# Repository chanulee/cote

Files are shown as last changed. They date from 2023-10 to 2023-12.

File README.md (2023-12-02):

# cote
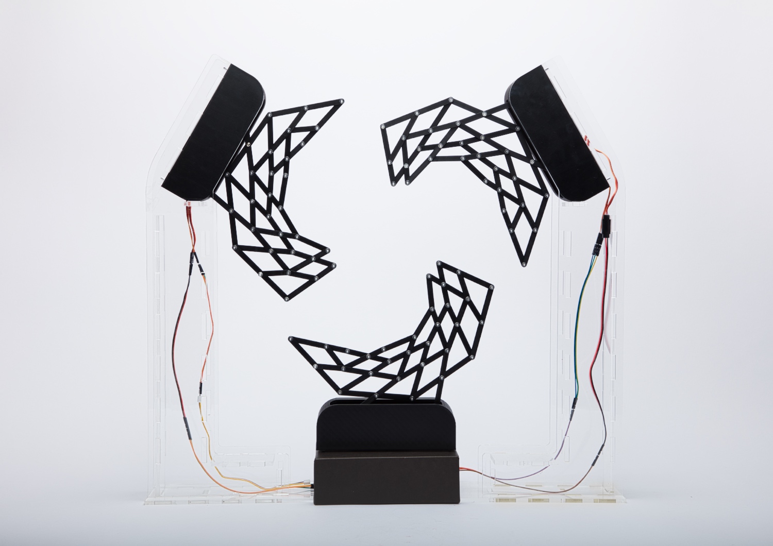
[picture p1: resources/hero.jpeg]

**_What is the value of telepresence if actual presence is neglected?_**  
  
During the pandemic, people became accustomed to virtual interactions. Driven by this shift, emerging technologies like Virtual Reality are focusing on translating real-world experiences entirely into the digital realm. Meanwhile, face-to-face interactions in the real world are dwindling. As an example, we often observe families in cafes who are each just looking at their smartphone without any conversation. What is the value of telepresence if actual presence is neglected? Tim Cook once said, if you're staring at smartphones more than into people's eyes, you're doing it wrong. We aim to gently promote humane and analog interaction through calm physical interfaces rather than attention-grabbing displays.  
  
In the Korean language, Hangeul, there's a phrase, "대화를 꽃피우다," which translates to 'blooming the conversation.' It's a beautiful term that likens a conversation to a flower.
  
With this ‘côte’ in the room, it can subtly make the space more vibrant and delightful.
## 1. File Directory
- demonov01: For final demo of Cyber Physical Systems module happened in 01 Nov 2023. oF, ino, wek files + recreation guide
- testcode: QC tools made for the project: osc communication, serial communication and motor control
- trials: Tried to develop it part-by-part, some succeeded and some didn't. For future works.
- resources: Images and circuit diagram
- appendix: About visionOSC's face datapoints
## 2. Specimen
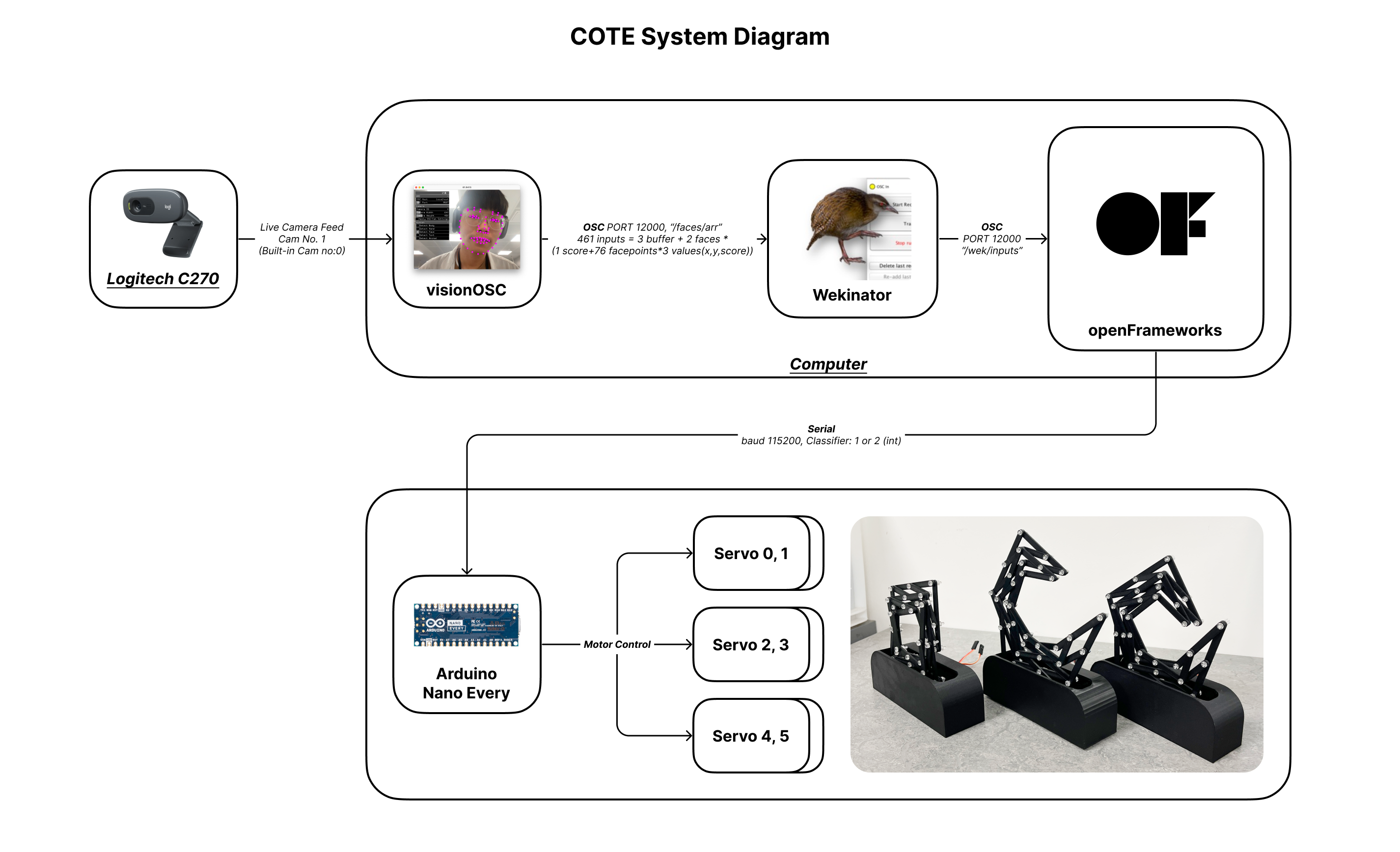
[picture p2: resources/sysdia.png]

### 2-1. Hardware
Check out fritzing file for more information.
- Arduino Nano Every (Arduino Mega 2560)
- Micro Servo MG90S (Black small one) * 6 (5V)
- Logitech C270 (HD 720p, proven to work as a video grabbing webcam) [Amazon](https://www.amazon.co.uk/dp/B01BGBJ8Y0?psc=1&ref=ppx_yo2ov_dt_b_product_details)
- PCA9685 Motor Driver (for power delivery, should be connected to power and arduino)
### 2-2. Software Requirements
- oF ofxOsc
- oF ofxGui (for Motor Testing)
- wekinator
- visionOSC [go to repo](https://github.com/LingDong-/VisionOSC)
- touchDesigner (not yet)
### 2-3. Features
- OSC Communication (visionOSC - wekinator - oF)
- Multiple OSC inputs
- OSC input parsing
- Combine multiple OSC messages and send (trying)
- Serial Communication (oF - Arduino)
- Motor Control
- Higher resolution (room to improve)
- Breathing motion
## 3. visionOSC data structure
Through several experiments with processing and wekinator OSC input monitor, I mapped out datapoints of [LingDong's visionOSC](https://github.com/LingDong-/VisionOSC).  
Check out [visionOscDatapoints folder](https://github.com/chanulee/cote-bloom/tree/main/appendix/visionOscDatapoints)
## 4. Future Works
- visionOSC & TouchDesigner --multiOSC--> oF --modifiedOSC--> wekinator --class--> oF --serial--> Arduino
- If openframeworks gets data directly from OSC not wekinator, we can make some decision before getting to the wekinator part - for example, maybe we can use certain model in certain condition - and we can exclude non-related data from the original OSC so machine learning part would be much more accurate with faster training/learning
- motor angle data 0-254 is mapped to 0-270 and finally about 1000-2000, but I'm still using 0-254 part so the resolution is quite low.
- nothing happens if there's nobody or one person in the cam view, everything stops. maybe we can add breathing motion when nothing is detected
- getting input from multiple addresses works in oF
- Selecting certain relevant OSC messages and then make them into a new message, sending it to wekinator - receiving and making new message kind of works, but the sending timing makes the message's size vary.
- Simple keypressedSerial is working on both Arduino nano and Mega - but servoAngleSerial doesn't work on Mega.
## 5. References
1. ofxOsc OSC Message documentaiton [openframeworks.cc](https://openframeworks.cc/documentation/ofxOsc/ofxOscMessage/)
2. ofxOsc bundling and parsing [forum.openframeworks.cc](https://forum.openframeworks.cc/t/osc-bundle-help/15404)
3. Based on research by H. Segerman [Paper](https://archive.bridgesmathart.org/2022/bridges2022-313.pdf)
## 6. Credits (Teammates)
- Hardware design engineering mainly by Jinhak Lee (IDE 23/25)
- Virtual prototyping, visual design and circuit diagram mainly by Poh Asdathorn (GIDv / Keio Media Design)
---
**Cyber Physical Systems, October-November 2023**    
Advisor Dr. Rebecca Stewart, Charlotte Slingsby, Dr Shayan Sharifi   
MSc Innovation Design Engineering   
Dyson School of Design Engineering, Imperial College London  
  
This module was funded by [Design Education Trust](https://www.designeducationtrust.org.uk/)

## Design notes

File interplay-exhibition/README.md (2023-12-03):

# System Guide for Cote
This system guide is for 
1. Software Setup
2. Hardware Installation
3. Maintenance
## 1. Software Setup for exhibition scenario 
### Essential Softwares
As Cote uses Apple's CoreML for face tracking, it is recommended to use Apple computers for the recreation. (If it's not possible, use faceOSC instead)  
1. Update your macbook and download Xcode. For this exhibition, I'm using macOS Sonoma and Xcode 15.
2. Download wekinator [here](http://www.wekinator.org/downloads/)
3. Download openFrameworks [here](https://openframeworks.cc/download/) and move it to main HD directory
4. Download visionOSC [here](https://github.com/LingDong-/VisionOSC)
### Essential Configurations
1. Download wek2ardu **oF** project from [here](https://github.com/chanulee/cote/tree/d52dcc5865f60ab2a6a312d79a86d98ab8011d35/demonov01), move the entire project to /myApps
2. Download coteClass.ino and upload it to **arduino**
3. Open **visionOSC**, turn off every detection except face detection, check port no 9527 (visionOSC to Wekinator) and save.
4. Connect the **webcam**, change the cammera number to get camera feed - do this every time you set up the system. (Due to refreshing and the fact that the camera number might vary on different system.
5. Open **wekinator**  

| Command | Input | Output |
| --- | --- | --- |
| `port` | 9527 | 12000 (default) |
| `add` | /faces/arr | /wek/outputs (default) |
| `#` | 232 | 1 |
|`description` | visionOSC -> Wek | Wek -> oF, Classifier with 2 classes |
## 2. Hardware Installation
- Macbook Pro 15 + USB-C Charger
- Control Box (arduino and PCA9685 motor driver) + Motor driver power
- Cote Modules * 3
- Webcam (Logitech C270) + USB-A to C Converter
## 3. Maintenance
### Setting up the artwork
Every hardware should be wired
1. Turn on the macbook, hold 'option' until it gets into bootcamp. Select macOS.
2. Open **visionOSC**, **wek2arduDebug**, **wekinator** and **macs fan control**
3. Setting up the webcam: On **visionOSC**, Press "Apply OSC/CAM Settings" button. Webcam's light turns on when successful.
4. In **wekinator**, press CMD+O or File/Open Project... and select interplay1p.wekproj. See if there's 232 inputs and the input light becomes green.
5. On the status bar, open **macs fan control**, set the fan speed to 4500 for both fans
6. Don't close the macbook all the way, it will prevent the heat to vent. Turn down the brightness and gently leave it open about 40 degree.
### End of the day...
1. Close **visionOSC**, **wek2arduDebug** and **wekinator**
2. Turn off the macbook and close it
### In case of...
- Hardware stuck: gently push the stuck part to the position it should be
- Software issue: please contact the creators
---
**InterPlay Exhibition Information**
- Venue: The Royal Society of Sculptors, Dora House 108 Old Brompton Rd, London SW7 3RA
- The Design Education Trust, Royal Society of Sculptors
  
Do you ever stop to reflect how much the design of motion in everyday objects affects your daily routine? Have you ever thought that behind everyday actions there was a creative mind designing the motion?  
Firstly you will encounter a selection of experimental kinetic objects from ‘Cyber Physical Systems’; a workshop of the joint programmes at Imperial College and the Royal College of Art of Innovation Design Engineering and Global Innovation Design. The devices use Arduino computers and Ai software to propose speculative kinetic designs that translate human behaviour into robotic motion.  
The Design Education Trust invites you to delve into a playful experience aiming to lift your spirits in these dour times. Join us between the 5th and 9th December to see our free INTERPLAY EXHIBITION at the ROYAL SOCIETY of SCULPTORS.

---
**Cyber Physical Systems, October-November 2023**    
Advisor Dr. Rebecca Stewart, Charlotte Slingsby, Dr Shayan Sharifi   
MSc Innovation Design Engineering   
Dyson School of Design Engineering, Imperial College London  
  
This module was funded by [Design Education Trust](https://www.designeducationtrust.org.uk/)

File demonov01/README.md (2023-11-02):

# Full Demo Set for cote - 01 Nov
## 1. Working Features
- visionOSC --OSC--> Wekinator --OSC--> oF --Serial--> Arduino
- Motor Control
- Higher resolution
- Mapping
- Breathing motion
- Blooming motion
## 2. Specimen
### 2-1. Hardware
Check out fritzing file for more information.
- Arduino Nano Every (Arduino Mega 2560)
- Micro Servo MG90S (Black small one) * 6 (5V)
- Logitech C270 (HD 720p, proven to work as a video grabbing webcam) [Amazon](https://www.amazon.co.uk/dp/B01BGBJ8Y0?psc=1&ref=ppx_yo2ov_dt_b_product_details)
- PCA9685 Motor Driver (for power delivery, should be connected to power and arduino)
### 2-2. Files Description
- cote2people: wekinator model (Neural Network) that determines if two people are standing still(1) or in  face-to-face(2)
- wek2ardu: oF app that gets OSC data from wekinator(1 or 2) and send it to arduino as serial message
- coteClass: Arduino file for getting the wekinator class
## 3. Recreate the Demo
1. Open **visionOSC**, connect Logitech C270, set CAM 1 and press 'Apply' and see if video grabbing is working (default output PORT 9527, address /faces/arr, 461 inputs for 2 faces)
2. Open **wekinator** app, open(CMD+O) a machine learning model cote2people, press 'Start Listening' and see if the data input is working, and 'Run' 
3. Open **Arduino** app, open coteClass.ino and upload it to arduino nano
4. Open **wek2ardu.xcodepro**, check if the arduino serial monitor is closed, and then build it
---
**Cyber Physical Systems, October-November 2023**    
Advisor Dr. Rebecca Stewart, Charlotte Slingsby, Dr Shayan Sharifi   
MSc Innovation Design Engineering   
Dyson School of Design Engineering, Imperial College London  
  
This module was funded by [Design Education Trust](https://www.designeducationtrust.org.uk/)

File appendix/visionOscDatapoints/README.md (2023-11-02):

# visionOSC data structure
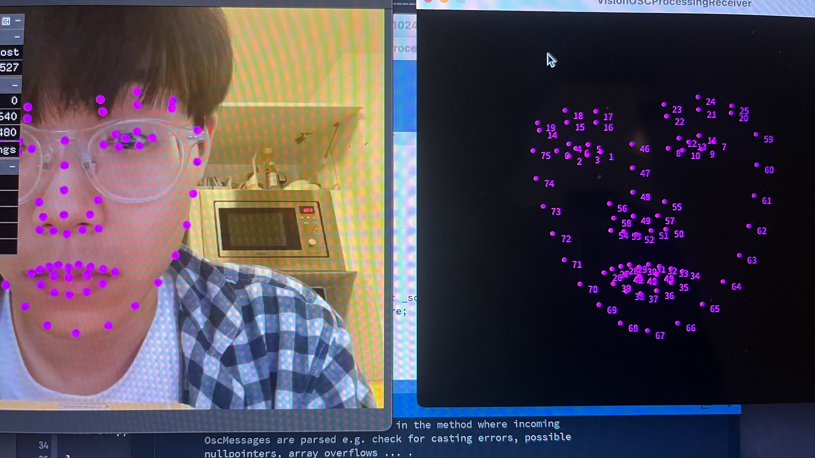
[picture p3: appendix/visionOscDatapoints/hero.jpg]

This is datapoint map/guide for faceOSC in LingDong's visionOSC [go to repo](https://github.com/LingDong-/VisionOSC).
- 232 inputs for one face, 461 inputs for two faces.
- Check out the .csv file for the specific datapoint chart.
- The score data: their numbers are 3, 6, 9...
- Buffer 0 data: 0, 1, 2
```
for (int i = 4; i <= 231; i++) {
    if (i % 3 != 0) { // Skip scores: 3, 6, 9, 12, 15, 18...
        int faceData = m.getArgAsInt(i);
        ofLog() << "facedata: " << faceData;
        wekMessage.addIntArg(faceData);
    }
}
```
## 1. Background
- There's datapoint description for poseOSC and handOSC but no enough documentation of faceOSC
- **No information about which data is related to certain part of the face**
- So this map might be helpful for various usecases such as refining relevant data for machine learning or media art
## 2. File structure
- **Modified processing file** that maps out the number of each datapoints on the face [original code at LingDong's repo](https://github.com/LingDong-/VisionOSC/tree/main/demos/VisionOSCProcessingReceiver)
- **csv file** with all the data points
- **screenshot** of wekinator input monitor
---
Chanwoo Lee  
MSc Innovation Design Engineering,  
Imperial College London  
Oct 2023

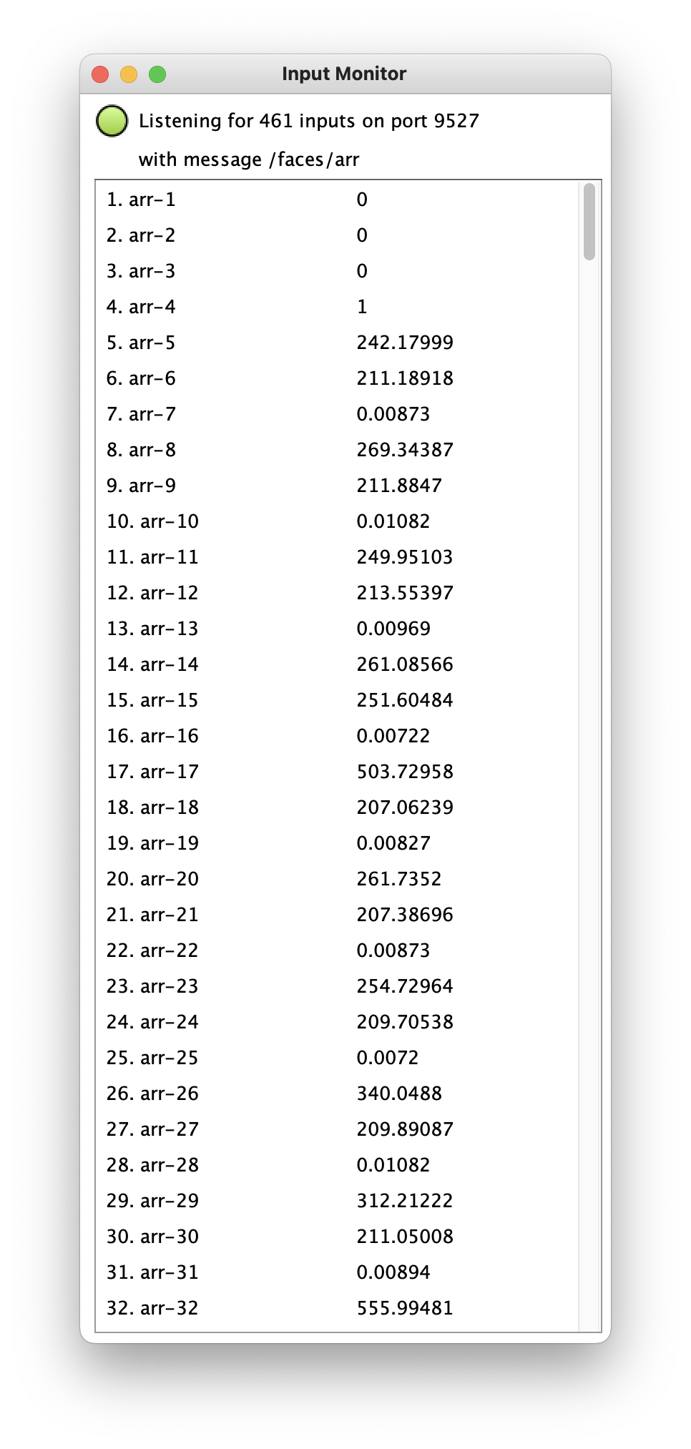
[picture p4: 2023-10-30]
appendix/visionOscDatapoints/2faces.png

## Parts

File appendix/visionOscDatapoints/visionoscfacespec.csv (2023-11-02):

no | data | bodypart
0 | width
1 | height
2 | faceno
3 | score face
4 | x | eyeL
5 | y | eyeL
6 | score | eyeL
7 | x | eyeL
8 | y | eyeL
9 | score | eyeL
10 | x | eyeL
11 | y | eyeL
12 | score | eyeL
13 | x | eyeL
14 | y | eyeL
15 | score | eyeL
16 | x | eyeL
17 | y | eyeL
18 | score | eyeL
19 | x | eyeL
20 | y | eyeL
21 | score | eyeL
22 | x | eyeL
23 | y | eyeL
24 | score | eyeL
25 | x | eyeR
26 | y | eyeR
27 | score | eyeR
28 | x | eyeR
29 | y | eyeR
30 | score | eyeR
31 | x | eyeR
32 | y | eyeR
33 | score | eyeR
34 | x | eyeR
35 | y | eyeR
36 | score | eyeR
37 | x | eyeR
38 | y | eyeR
39 | score | eyeR
40 | x | eyeR
41 | y | eyeR
42 | score | eyeR
43 | x | eyeR
44 | y | eyeR
45 | score | eyeR
46 | x | eyebrowL
47 | y | eyebrowL
48 | score | eyebrowL
49 | x | eyebrowL
50 | y | eyebrowL
51 | score | eyebrowL
52 | x | eyebrowL
53 | y | eyebrowL
54 | score | eyebrowL
55 | x | eyebrowL
56 | y | eyebrowL
57 | score | eyebrowL
58 | x | eyebrowL
59 | y | eyebrowL
60 | score | eyebrowL
61 | x | eyebrowL
62 | y | eyebrowL
63 | score | eyebrowL
64 | x | eyebrowR
65 | y | eyebrowR
66 | score | eyebrowR
67 | x | eyebrowR
68 | y | eyebrowR
69 | score | eyebrowR
70 | x | eyebrowR
71 | y | eyebrowR
72 | score | eyebrowR
73 | x | eyebrowR
74 | y | eyebrowR
75 | score | eyebrowR
76 | x | eyebrowR
77 | y | eyebrowR
78 | score | eyebrowR
79 | x | eyebrowR
80 | y | eyebrowR
81 | score | eyebrowR
82 | x | mouth
83 | y | mouth
84 | score | mouth
85 | x | mouth
86 | y | mouth
87 | score | mouth
88 | x | mouth
89 | y | mouth
90 | score | mouth
91 | x | mouth
92 | y | mouth
93 | score | mouth
94 | x | mouth
95 | y | mouth
96 | score | mouth
97 | x | mouth
98 | y | mouth
99 | score | mouth
100 | x | mouth
101 | y | mouth
102 | score | mouth
103 | x | mouth
104 | y | mouth
105 | score | mouth
106 | x | mouth
107 | y | mouth
108 | score | mouth
109 | x | mouth
110 | y | mouth
111 | score | mouth
112 | x | mouth
113 | y | mouth
114 | score | mouth
115 | x | mouth
116 | y | mouth
117 | score | mouth
118 | x | mouth
119 | y | mouth
120 | score | mouth
121 | x | mouth
122 | y | mouth
123 | score | mouth
124 | x | mouth
125 | y | mouth
126 | score | mouth
127 | x | mouth
128 | y | mouth
129 | score | mouth
130 | x | mouth
131 | y | mouth
132 | score | mouth
133 | x | mouth
134 | y | mouth
135 | score | mouth
136 | x | mouth
137 | y | mouth
138 | score | mouth
139 | x | mouth
140 | y | mouth
141 | score | mouth
142 | x | nose
143 | y | nose
144 | score | nose
145 | x | nose
146 | y | nose
147 | score | nose
148 | x | nose
149 | y | nose
150 | score | nose
151 | x | nose
152 | y | nose
153 | score | nose
154 | x | nose
155 | y | nose
156 | score | nose
157 | x | nose
158 | y | nose
159 | score | nose
160 | x | nose
161 | y | nose
162 | score | nose
163 | x | nose
164 | y | nose
165 | score | nose
166 | x | nose
167 | y | nose
168 | score | nose
169 | x | nose
170 | y | nose
171 | score | nose
172 | x | nose
173 | y | nose
174 | score | nose
175 | x | nose
176 | y | nose
177 | score | nose
178 | x | nose
179 | y | nose
180 | score | nose
181 | x | face outline
182 | y | face outline
183 | score | face outline
184 | x | face outline
185 | y | face outline
186 | score | face outline
187 | x | face outline
188 | y | face outline
189 | score | face outline
190 | x | face outline
191 | y | face outline
192 | score | face outline
193 | x | face outline
194 | y | face outline
195 | score | face outline
196 | x | face outline
197 | y | face outline
198 | score | face outline
199 | x | face outline
200 | y | face outline
201 | score | face outline
202 | x | face outline
203 | y | face outline
204 | score | face outline
205 | x | face outline
206 | y | face outline
207 | score | face outline
208 | x | face outline
209 | y | face outline
210 | score | face outline
211 | x | face outline
212 | y | face outline
213 | score | face outline
214 | x | face outline
215 | y | face outline
216 | score | face outline
217 | x | face outline
218 | y | face outline
219 | score | face outline
220 | x | face outline
221 | y | face outline
222 | score | face outline
223 | x | face outline
224 | y | face outline
225 | score | face outline
226 | x | face outline
227 | y | face outline
228 | score | face outline
229 | x | face outline
230 | y | face outline
231 | score | face outline
232 | score face
233 | x | eyeL
234 | y | eyeL
235 | score | eyeL
236 | x | eyeL
237 | y | eyeL
238 | score | eyeL
239 | x | eyeL
240 | y | eyeL
241 | score | eyeL
242 | x | eyeL
243 | y | eyeL
244 | score | eyeL
245 | x | eyeL
246 | y | eyeL
247 | score | eyeL
248 | x | eyeL
249 | y | eyeL
250 | score | eyeL
251 | x | eyeL
252 | y | eyeL
253 | score | eyeL
254 | x | eyeR
255 | y | eyeR
256 | score | eyeR
257 | x | eyeR
258 | y | eyeR
259 | score | eyeR
260 | x | eyeR
261 | y | eyeR
262 | score | eyeR
263 | x | eyeR
264 | y | eyeR
265 | score | eyeR
266 | x | eyeR
267 | y | eyeR
268 | score | eyeR
269 | x | eyeR
270 | y | eyeR
271 | score | eyeR
272 | x | eyeR
273 | y | eyeR
274 | score | eyeR
275 | x | eyebrowL
276 | y | eyebrowL
277 | score | eyebrowL
278 | x | eyebrowL
279 | y | eyebrowL
280 | score | eyebrowL
281 | x | eyebrowL
282 | y | eyebrowL
283 | score | eyebrowL
284 | x | eyebrowL
285 | y | eyebrowL
286 | score | eyebrowL
287 | x | eyebrowL
288 | y | eyebrowL
289 | score | eyebrowL
290 | x | eyebrowL
291 | y | eyebrowL
292 | score | eyebrowL
293 | x | eyebrowR
294 | y | eyebrowR
295 | score | eyebrowR
296 | x | eyebrowR
297 | y | eyebrowR
298 | score | eyebrowR
299 | x | eyebrowR
300 | y | eyebrowR
301 | score | eyebrowR
302 | x | eyebrowR
303 | y | eyebrowR
304 | score | eyebrowR
305 | x | eyebrowR
306 | y | eyebrowR
307 | score | eyebrowR
308 | x | eyebrowR
309 | y | eyebrowR
310 | score | eyebrowR
311 | x | mouth
312 | y | mouth
313 | score | mouth
314 | x | mouth
315 | y | mouth
316 | score | mouth
317 | x | mouth
318 | y | mouth
319 | score | mouth
320 | x | mouth
321 | y | mouth
322 | score | mouth
323 | x | mouth
324 | y | mouth
325 | score | mouth
326 | x | mouth
327 | y | mouth
328 | score | mouth
329 | x | mouth
330 | y | mouth
331 | score | mouth
332 | x | mouth
333 | y | mouth
334 | score | mouth
335 | x | mouth
336 | y | mouth
337 | score | mouth
338 | x | mouth
339 | y | mouth
340 | score | mouth
341 | x | mouth
342 | y | mouth
343 | score | mouth
344 | x | mouth
345 | y | mouth
346 | score | mouth
347 | x | mouth
348 | y | mouth
349 | score | mouth
350 | x | mouth
351 | y | mouth
352 | score | mouth
353 | x | mouth
354 | y | mouth
355 | score | mouth
356 | x | mouth
357 | y | mouth
358 | score | mouth
359 | x | mouth
360 | y | mouth
361 | score | mouth
362 | x | mouth
363 | y | mouth
364 | score | mouth
365 | x | mouth
366 | y | mouth
367 | score | mouth
368 | x | mouth
369 | y | mouth
370 | score | mouth
371 | x | nose
372 | y | nose
373 | score | nose
374 | x | nose
375 | y | nose
376 | score | nose
377 | x | nose
378 | y | nose
379 | score | nose
380 | x | nose
381 | y | nose
382 | score | nose
383 | x | nose
384 | y | nose
385 | score | nose
386 | x | nose
387 | y | nose
388 | score | nose
389 | x | nose
390 | y | nose
391 | score | nose
392 | x | nose
393 | y | nose
394 | score | nose
395 | x | nose
396 | y | nose
397 | score | nose
398 | x | nose
399 | y | nose
400 | score | nose
401 | x | nose
402 | y | nose
403 | score | nose
404 | x | nose
405 | y | nose
406 | score | nose
407 | x | nose
408 | y | nose
409 | score | nose
410 | x | face outline
411 | y | face outline
412 | score | face outline
413 | x | face outline
414 | y | face outline
415 | score | face outline
416 | x | face outline
417 | y | face outline
418 | score | face outline
419 | x | face outline
420 | y | face outline
421 | score | face outline
422 | x | face outline
423 | y | face outline
424 | score | face outline
425 | x | face outline
426 | y | face outline
427 | score | face outline
428 | x | face outline
429 | y | face outline
430 | score | face outline
431 | x | face outline
432 | y | face outline
433 | score | face outline
434 | x | face outline
435 | y | face outline
436 | score | face outline
437 | x | face outline
438 | y | face outline
439 | score | face outline
440 | x | face outline
441 | y | face outline
442 | score | face outline
443 | x | face outline
444 | y | face outline
445 | score | face outline
446 | x | face outline
447 | y | face outline
448 | score | face outline
449 | x | face outline
450 | y | face outline
451 | score | face outline
452 | x | face outline
453 | y | face outline
454 | score | face outline
455 | x | face outline
456 | y | face outline
457 | score | face outline
458 | x | face outline
459 | y | face outline
460 | score | face outline

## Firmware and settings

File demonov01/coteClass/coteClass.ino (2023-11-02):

#include <Servo.h>

/*---Servo Declare---*/
// twelve servo objects can be created on most boards
Servo servoSet1;
int lM1 = 15;
int rM1 = 16;
Servo servoSet2;
int lM2 = 17;
int rM2 = 18;
Servo servoSet3;
int lM3 = 19;
int rM3 = 20;

int angle = 0;

/*---State---*/
// enum State {
//   Idle,
//   Ascending,
//   BigBreathe,
//   Descending,
//   Idle2,
//   Ascending2,
//   BigBreathe2,
//   Descending2
// };
// State state = Idle;

/*---State in number---*/
int state = 3;
/*
  3Idle,
  4Ascending,
  5BigBreathe,
  6Descending,
  7Idle2,
  8Ascending2,
  9BigBreathe2,
  10Descending2
*/

/*---Time Management---*/
unsigned long previousMillis = 0;
const long interval = 10;  // Interval in milliseconds
bool inhale = true;

int wekClass = 0;

void setup() {
  Serial.begin(115200);
  Serial.println("Serial INIT");
}

void loop() {
if (Serial.available()>0) {
  // Serial.println("Serial working");

  /*---read from oF---*/
  wekClass = Serial.read() - '0' + 48; // 1 or 2
  Serial.println(wekClass);

  switch (state) {
    case 3: //Idle
      breathe(5, 25); 
      if (wekClass == 2) {
        state = 4;
      }
      break;
    case 4: //Ascending
      if (angle < 105) {
        angle++;
        servoSync(angle);
      } else {
        state = 5;
      }
      break;
    case 5: //BigBreathe
      breathe(105, 130);  // Big breathe range
      if (wekClass == 1) {
        state = 6;
      }
      break;
    case 6: //Descending
      if (angle < 245) {
        angle++;
        servoSync(angle);
      } else {
        state = 7;
      }
      break;
    case 7: //Idle2
      breathe(245, 265); 
      if (wekClass == 2) {
        state = 8;
      }
      break;
    case 8: //Ascending2
        Serial.println(state);
      if (angle > 140) {
        angle--;
        servoSync(angle);
      } else {
        state = 9;
      }
      break;
    case 9: //Big breathe2
      breathe(140, 165);  // Big breathe range
      if (wekClass == 1) {
        state = 10;
      }
      break;
    case 10: //Descending2
      if (angle > 5) {
        angle--;
        servoSync(angle);
      } else {
        state = 3;
      }
      break;

  }

  // switch (state) {
  //   case Idle:
  //       Serial.println(state);
  //     breathe(5, 30); 
  //     if (wekClass == 2) {
  //       state = Ascending;
  //     }
      
  //     break;
  //   case Ascending:
  //     // Increment i gradually until it reaches 105
  //         Serial.println(state);
  //     if (angle < 105) {
  //       angle++;
  //     } else {
  //       state = BigBreathe;
  //     }
  //     // if (wekClass == 1) {
  //     //   state = Descending2;
  //     // }
  //     break;
  //   case BigBreathe:
  //       Serial.println(state);
  //     breathe(105, 130);  // Big breathe range
  //     if (wekClass == 1) {
  //       state = Descending;
  //     }
  //     break;
  //   case Descending:
  //       Serial.println(state);
  //     // Increment i gradually until it reaches 105
  //     if (angle < 240) {
  //       angle++;
  //     } else {
  //       state = Idle2;
  //     }
  //     // if (wekClass == 2) {
  //     //   state = Ascending2;
  //     // }
  //     break;
  //   case Idle2:
  //       Serial.println(state);
  //     breathe(240, 265); 
  //     if (wekClass == 2) {
  //       state = Ascending2;
  //     }
  //     break;
  //   case Ascending2:
  //       Serial.println(state);
  //     if (angle > 140) {
  //       angle--;
  //     } else {
  //       state = BigBreathe2;
  //     }
  //     // if (wekClass == 1) {
  //     //   state = Descending;
  //     // }
  //     break;
  //   case BigBreathe2:
  //       Serial.println(state);
  //     breathe(140, 165);  // Big breathe range
  //     if (wekClass == 1) {
  //       state = Descending2;
  //     }
  //     break;
  //   case Descending2:
  //       Serial.println(state);
  //     if (angle > 5) {
  //       angle--;
  //     } else {
  //       state = Idle;
  //     }
  //     // if (wekClass == 1) {
  //     //   state = Descending;
  //     // }
  //     break;
  // }

  } 
  // else {
  //   switch (state) {
  //   case 3: //Idle
  //     breathe(5, 25); 
  //     break;
  //   case 4: //Ascending
  //     breathe(5, 25);
  //     break;
  //   case 5: //BigBreathe
  //     breathe(5, 25);
  //     break;
  //   case 6: //Descending
  //     breathe(245, 265);
  //     break;
  //   case 7: //Idle2
  //     breathe(245, 265); 
  //     break;
  //   case 8: //Ascending2
  //     breathe(245, 265);
  //     break;
  //   case 9: //Big breathe2
  //     breathe(245, 265);
  //     break;
  //   case 10: //Descending2
  //     breathe(5, 25); 
  //     break;
  //   }
  // }
}

void breathe(int minAng, int maxAng) {
  unsigned long currentMillis = millis();
  if (currentMillis - previousMillis >= interval) {
    previousMillis = currentMillis;

    if (inhale) {
      angle++;
      if (angle >= maxAng) inhale = false;
    } else {
      angle--;
      if (angle <= minAng) inhale = true;
    }
    servoSync(angle);
    // Serial.println(i);
  }
}


/*--- Move multiple motors together---*/
void servoSync(int leftAngle){
  servoSetDetach();
  if (leftAngle > 135) {
    servoLeftMove(leftAngle);
  } else {
    int rightAngle = leftAngle;
    servoRightMove(rightAngle);
  }
}

// /*--- Simple servo control ---*/
// void servoControl(int leftAngle, int leftMotor, int rightMotor){
//   if (leftAngle > 135) {
//     servo.detach();
//     servo.attach(leftMotor);
//     servo.writeMicroseconds(map(leftAngle - 89,47,181,1000,2450));
//     // Serial.print("L ");
//     // Serial.println(map(leftAngle - 89,47,181,1000,2000));
//   } else {
//     int rightAngle = leftAngle;
//     // Serial.println(rightAngle);
//     servo.detach();
//     servo.attach(rightMotor);
//     servo.writeMicroseconds(map(rightAngle,0,135,600,2000));
//     // Serial.print("R ");
//     // Serial.println(map(rightAngle,0,135,1000,2000));
//   }
// }


/*--- Basic Controls ---*/
void servoSetDetach() {
    servoSet1.detach();
    servoSet2.detach();
    servoSet3.detach();
}

void servoLeftMove(int leftAngle){
    servoSet1.attach(lM1);
    servoSet2.attach(lM2);
    servoSet3.attach(lM3);

    servoSet1.writeMicroseconds(map(leftAngle - 89,47,181,1000,2450));
    servoSet2.writeMicroseconds(map(leftAngle - 89,47,181,1000,2450));
    servoSet3.writeMicroseconds(map(leftAngle - 89,47,181,1000,2450));
}

void servoRightMove(int rightAngle){
    servoSet1.attach(rM1);
    servoSet2.attach(rM2);
    servoSet3.attach(rM3);

    servoSet1.writeMicroseconds(map(rightAngle,0,135,600,2000));
    servoSet2.writeMicroseconds(map(rightAngle,0,135,600,2000));
    servoSet3.writeMicroseconds(map(rightAngle,0,135,600,2000));
}

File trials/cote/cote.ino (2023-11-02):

#include <Servo.h>

Servo servo;
Servo servoSet1;
Servo servoSet2;
Servo servoSet3;
// twelve servo objects can be created on most boards

unsigned long previousMillis = 0;
const long interval = 250;  // Interval in milliseconds
int i = 45;
bool ascending = true;

void setup() {
  Serial.begin(115200);
  Serial.println("Serial INIT");
}

void loop() {
if (Serial.available()>0) {
    // Serial.println("Serial working");

    /*---read from oF---*/
    int serialAngle = Serial.read() - '0' + 48;

    int angleMap = map(serialAngle, 0,254,0,270); //0 to 135 and 135 to 270

    servoSync(angleMap, 15, 16, 17, 18); //small right

  } 
}

/*--- Simple servo control ---*/
void servoControl(int leftAngle, int leftMotor, int rightMotor){
  if (leftAngle > 135) {
    servo.detach();
    servo.attach(leftMotor);
    servo.writeMicroseconds(map(leftAngle - 89,47,181,1000,2450));
    // Serial.print("L ");
    // Serial.println(map(leftAngle - 89,47,181,1000,2000));
  } else {
    int rightAngle = leftAngle;
    // Serial.println(rightAngle);
    servo.detach();
    servo.attach(rightMotor);
    servo.writeMicroseconds(map(rightAngle,0,135,600,2000));
    // Serial.print("R ");
    // Serial.println(map(rightAngle,0,135,1000,2000));
  }
}

/*--- Move multiple motors together---*/
void servoSync(int leftAngle, int lM1, int rM1, int lM2, int rM2, int lM3, int rM3){
  servoSetDetach();
  if (leftAngle > 135) {
    servoLeftMove(leftAngle, lM1, lM2, lM3);
  } else {
    int rightAngle = leftAngle;
    servoRightMove(rightAngle,rM1, rM2, rM3 )
  }
}

void servoSetDetach() {
    servoSet1.detach();
    servoSet2.detach();
    servoSet3.detach();
}

void servoLeftMove(int leftAngle, int lM1, int lM2, int lM3){
    servoSet1.attach(lM1);
    servoSet2.attach(lM2);
    servoSet3.attach(lM3);

    servoSet1.writeMicroseconds(map(leftAngle - 89,47,181,1000,2450));
    servoSet2.writeMicroseconds(map(leftAngle - 89,47,181,1000,2450));
    servoSet3.writeMicroseconds(map(leftAngle - 89,47,181,1000,2450));
}

void servoRightMove(int rightAngle, int rM1, int rM2, int rM3){
    servoSet1.attach(rM1);
    servoSet2.attach(rM2);
    servoSet3.attach(rM3);

    servoSet1.writeMicroseconds(map(rightAngle,0,135,600,2000));
    servoSet2.writeMicroseconds(map(rightAngle,0,135,600,2000));
    servoSet3.writeMicroseconds(map(rightAngle,0,135,600,2000));
}

// void breathe(int leftMotor, int rightMotor){
void breathe(){
  unsigned long currentMillis = millis();

  if (currentMillis - previousMillis >= interval) {
    previousMillis = currentMillis;
    if (ascending) {
      i++;
      if (i >= 135) ascending = false;
    } else {
      i--;
      if (i <= 45) ascending = true;
    }
    // servoControl(i, leftMotor, rightMotor);
    Serial.println(i);
  }

}

// JUST IN CASE //

// void zenBreathe(int leftAngle){
//   // everything in sync
//   servoControl(angleMap, 5, 6);
//   servoControl(angleMap, 5, 6);
//   servoControl(angleMap, 5, 6);
// }


// SETTINGS //
void initialSet(int leftMotor, int rightMotor){
  servo.attach(leftMotor);
  servo.attach(rightMotor);
  servo.write(0);
}

/*
EXPIRED 
*/

// void motorControl180(int leftAngle, int leftMotor, int rightMotor){
//     if (leftAngle > 135) {
//       servo.detach();
//       servo.attach(leftMotor);
//       servo.write(leftAngle - 89);

//     } else {
//       int rightAngle = leftAngle;
//       // Serial.println(rightAngle);
//       servo.detach();
//       servo.attach(rightMotor);
//       servo.write(rightAngle);
//     }
// }

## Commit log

2023-10-31 Testing code - oF to ardu serial and motor angle
2023-10-31 circuit diagram by Poh
    [circuit diagram.fzz]
2023-10-31 Create cote.ino
    main arduino code
